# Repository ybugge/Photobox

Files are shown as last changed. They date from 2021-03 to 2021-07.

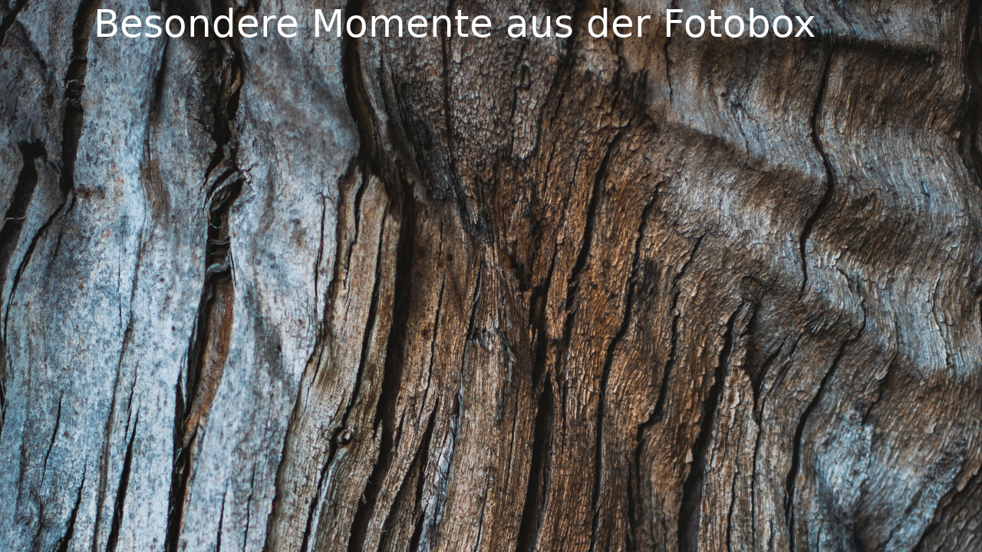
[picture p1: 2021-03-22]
Diashow/fromPhotobox/frame.png

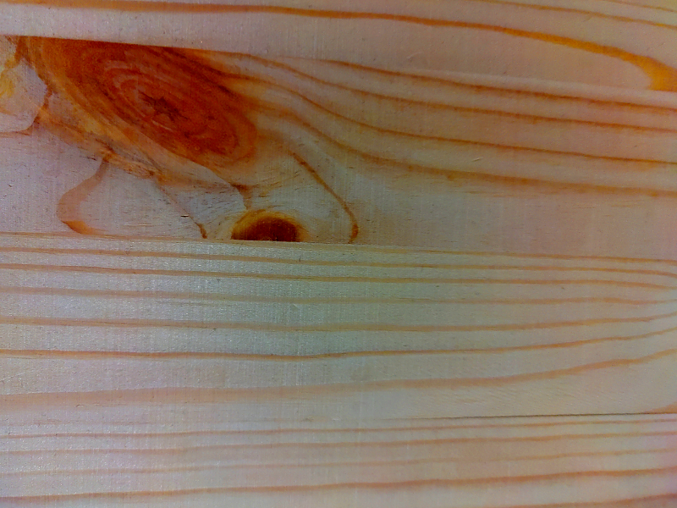
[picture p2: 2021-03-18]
Resources/PageTitlePicture/orig.png

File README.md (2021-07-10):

# Fotobox
Die Software wurde für den Raspberry PI entwickelt. Getestet wurde es auf dem Raspberry Pi 3 Model B+.
Entwickelt wurde es mit PyCharm in LinuxMint. Unter Windows funktioniert die Software nicht, da CUPS nicht von 
Windows unterstützt wird.

## Hardware
- Raspberry Pi 3 Model B+ -> https://www.raspberrypi.org/products/raspberry-pi-3-model-b-plus/
- Raspberry Pi High Quality Camera -> https://www.raspberrypi.org/products/raspberry-pi-high-quality-camera/
- Raspberry Pi Touch Display -> https://www.raspberrypi.org/products/raspberry-pi-touch-display/
- 16 GB SD-Karte
- Mini Wireless Keyboard Remote X8 -> http://www.riitek.com/product/x8.html
- Fritz!Box 4020 -> https://avm.de/produkte/fritzbox/fritzbox-4020/
- Canon SELPHY CP1300 -> https://www.canon.de/printers/selphy-cp1300/
- 2 USB Sticks für Fotos und Musik

Optional:
- UGREEN Externe USB Soundkarte -> https://www.amazon.de/UGREEN-Externe-Soundkarte-Computer-External/dp/B01N905VOY/ref=sr_1_10
- Kühlung -> https://www.amazon.de/MakerHawk-R%C3%BCstungskoffer-Himbeer-Pi-Metallgeh%C3%A4use-Doppel-L%C3%BCfter-Aluminiumlegierung-integrierter/dp/B07M7M53LT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

### Gehäuse
- Holzbox (außen: 40x30x24cm)(innen:37,5x27,5x21cm) -> https://www.amazon.de/LAUBLUST-Gro%C3%9Fe-Holzkiste-Deckel-Geschenk-Verpackung/dp/B016UYX344
- Kistengriffe -> https://www.amazon.de/ueetek-Edelstahl-schwere-stabile-Toolbox/dp/B079CF95Z9
- Aufnahme für das Dreibein -> https://www.amazon.de/Stagg-9709-Externer-Boxenflansch-Anschrauben/dp/B000OR5YE6
- Dreibein -> https://www.amazon.de/gp/product/B07PXQQ6Q1/ref=ppx_yo_dt_b_asin_title_o06_s00
- Schloss -> https://www.amazon.de/gp/product/B083LKFKQW/ref=ppx_yo_dt_b_asin_title_o07_s00
- Schnapper (damit der Deckel zu bleibt) -> https://www.amazon.de/gp/product/B07M67WJJR/ref=ppx_yo_dt_b_asin_title_o07_s01
- Rundstab: 20,5cm x 0,5cm (Essstäbchen)
- Brillenputztuch 
- Sperrholz (37,5cm x 19,0cm x 0,4cm)
- Aufbewahrungsbox (24,5cm x 18cm x 16 cm) (Really Useful Box Aufbewahrungsbox 3C 3 L)-> https://www.ebay.de/itm/362899377740?hash=item547e7d0e4c:g:udIAAOSwOQpftiw6

####Holzbox Maße:
Ausrichtung: Deckel zu mir gerichtet und wenn er offen ist, liegt er auf dem Boden.

Außen (mit Deckel): 
- 232mm (Tief)
- 293mm (Hoch)
- 395mm (Breit)

Außen (ohne Deckel):
- 197mm (Tief)
- 293mm (Hoch)
- 395mm (Breit)

Innen (mit Deckel):
- 212mm (Tief)
- 278mm (Hoch)
- 378mm (Breit)

Innen (ohne Deckel):
- 185mm (Tief)
- 278mm (Hoch)
- 378mm (Breit)

Wandstärke: ca. 9mm

#####Löcher:

Drucker:
- 120mm (Tief) x 35mm (Breit)
- Pos: 21cm (von vorne-Außen) x 15mm (von unten-Außen) 

Bildschirm:
- 105mm (Hoch) x 175mm (Breit)
- Pos: Unten anliegend mittig 

Kamera:
- 50mm (Hoch) x 42mm(Breit)
- Pos: 62mm (von oben Außen) x mittig

Stromanschluss:
- 29mm(Breit) x 56 (Hoch)
- Pos: 20mm (Von der Seite-Außen) 81mm (von Hinten-Außen)

##### Position:

Zwischenboden:
- Pos: 90mm (von unten-Innen) (Unterkante des 3D-Objekts)

Steckdose:
- Pos: 30mm (von vorne-Innen) so hoch wie möglich

Drucker-Grundplatte:
- Pos: 61mm (von Seite-Innen) so weit hinten wie möglich
   
### Elektrik
- Verteiler 4fach -> https://www.amazon.de/REV-STECKDOSE-PlanoLuxe-Mehrfachsteckdose-Innenbereich/dp/B00C25WRZW
- Kabel -> https://www.amazon.de/Bachmann-202275-Eurozuleitung/dp/B001ZT6VP8
- Hauptschalter mit Sicherung (Trennt Neutralleiter und Last) -> https://www.amazon.de/Hifi-Lab-Einbau-Stecker-Einbau-Buchse-Kaltgeräte-Buchse/dp/B01H5MK3OI
- Lichtschalter -> https://www.amazon.de/gp/product/B074VCBVKJ/ref=ppx_yo_dt_b_asin_title_o08_s00
- Lampen (2 Stück) -> https://www.reichelt.de/deckenleuchte-8-w-560-lm-3000-k-oval-vt-1311-p201362.html?&trstct=pos_3&nbc=1

### Optionale Kleinigkeiten
- Live Soundcard V8 -> https://www.ebay.de/itm/203511744223?hash=item2f623ec6df:g:gg4AAOSwn5lg3nA4
- Mikrofon
- Fotostudio (2.6M x 3M) -> https://www.amazon.de/gp/product/B0799BQJWX/ref=ppx_yo_dt_b_asin_title_o00_s00
- JBL Partybox 300 (2 mal) -> https://de.jbl.com/party-lautsprecher/JBL+PartyBox+300.html
- LTE Router -> https://www.amazon.de/TP-Link-M7200-Download-kompatibel-europ%C3%A4ischen-schwarz/dp/B079GZNQ2B/ref=sr_1_6

##Install
Die nachfolgende Instalation wurde mit LinuxMint durchgeführt.
Der Raspberry Pi wird ab jetzt Pi genannt. 

Auf LinuxMint:
````
$ sudo apt update
$ yes | sudo apt install rpi-imager
$ rpi-imager
````
- Operation Systenm = Raspberry PI OS (32-bit) (Recommanded)
- SD Card = Die zu verwendete SD-Karte
- "Write"
- "Yes"
- SD-Karte entnehmen und in den Pi stecken
- Raspberry Pi einschalten

Auf Raspberry Pi:
- Welcome to Raspberry Pi:
  - IP-Adresse aufschreiben: 192.168.188.22
  - Klicken: "Next"
  - Sprache einstellen und "Next" 
  - neues Passwort vergeben und "Next"
  - Bildschirmeinstellungen -> "Next"
  - Wifi eingeben wenn nötig. In meinem Fall ist der Pi mit dem Router über LAN verbunden 
  - Updates -> Next 
  - Pi neustarten 
 - Starten: "Raspberry-Pi-Konfiguration" unter "Start > Einstellungen"
   - Tab -> "System"
   - Aktivieren: "Auf Netzwerk warten"
   - Tab -> "Schnittstellen"
   - Aktivieren: "Kamera"
   - Aktivieren: "SSH"
   - Tab -> "Display"
   - Deaktivieren: "Screen Blanking"
   - "OK"
   - Restart? -> "Ja"
  
Auf der Fritzbox
- LinuxMint: mit der Fritzbox verbinden
- Browser öffnen und die Seite "fritz.box/" aufrufen
- Einloggen
- Heimnetz > Netzwerk > Pi raussuchen bsp:192.168.188.22 > Auf "Stift" klicken
- "Name" = photobox
- Aktivieren: "Diesem Netzwerkgerät immer die gleiche IPv4-Adresse zuweisen."
- "OK"

Auf LinuxMint:
- Terminal öffnen 
````
$ ssh pi@photobox
$ yes
$ -> Passwort eingeben 
$ sudo apt update
$ yes | sudo apt upgrade 
$ yes | sudo apt install git
$ git clone https://github.com/ybugge/Photobox.git
$ cd Photobox
$ ./setupPhotobox.sh
````

Netzwerk nach einer Minute neu starten:
````
$ sudo crontab -e
@reboot /bin/sleep 60; /home/pi/Photobox/ShellScripts/restartNetwork.sh
STR+X -> Y -> ENTER 
````

##Drucker einrichten: Canon SELPHY CP1300 (W-LAN)
Quelle: 
- https://raspberrytips.com/install-printer-raspberry-pi/
- https://youtu.be/Gd0RKYRNJmo?t=570

PPD-Profile:
- 1.) https://cloud.voss.earth/index.php/s/SAi2M2na5KtR3gm -> https://www.voss.earth/2018/08/31/kurztipp-canon-selphy-wlan-drucker-cp910-oder-cp1300-unter-linux-cups-verwenden/
- 2.) https://www.objektiv-guide.de/icc-profil-canon-selphy/ -> Forum: https://www.dslr-forum.de/showthread.php?s=c6704e889a4db8e35e09f900192a341d&t=1865472&page=4

Browser->Pi: localhost:631

- Drucker und Klassen hinzufügen
- Drucker hinzufügen
- Eingabe: Benutzername und Passwort
- Drucker auswählen: (Netzwerkdrucker) Canon SELPHY CP1300 (Canon SELPHY CP1300)  
- Weiter
- Weiter
- PPD-Datei: Datei auswählen
- Photobox/PrinterPPD/Canon_SELPHY_CP1300.ppd
- Öffnen
- Drucker hinzufügen
- Color Mode: Color
- Media Size: Postcard.Fullbleed
- MediaType: Any
- Standardeinstellungen festlegen 

Hinweis:
1. Folgende Einstellung sollte an dem Drucker vorgenommen werden:
- WLAN-Einstellungen > Verbindungsmethode > Über WLAN-Netzwerk = Mit der Fritzbox verbinden.
- Setup > Drucker Setup >auto.Abschalten = Aus

# Diashow Client

## Hardware
- Raspberry Pi Zero W -> https://www.raspberrypi.org/products/raspberry-pi-zero-w/
- 16GB SD-Karte
- TV

## Install
Die nachfolgende Instalation wurde mit LinuxMint durchgeführt.
Der Raspberry Pi Zero W wird ab jetzt Pi genannt. 

Auf LinuxMint:
````
$ sudo apt update
$ yes | sudo apt install rpi-imager
$ rpi-image
````
- Operation Systenm = Raspberry PI OS (32-bit) (Recommanded)
- SD Card = Die zu verwendete SD-Karte
- "Write"
- "Yes"
- SD-Karte erneut in LinuxMint stecken
  - Ordner "boot" öffnen 
  - Datei "ssh" erstellen
  - Datei "wpa_supplicant.conf" erstellen 
  - folgendes eintragen: siehe https://www.raspberrypi.org/documentation/configuration/wireless/headless.md
```
ctrl_interface=DIR=/var/run/wpa_supplicant GROUP=netdev
update_config=1
country=<Insert 2 letter ISO 3166-1 country code here>

network={
 ssid="<Name of your wireless LAN>"
 psk="<Password for your wireless LAN>"
}
```
- SD-Karte entnehmen und in den Pi stecken
- Raspberry Pi einschalten

Auf Linux Mint:
- Terminal öffnen:
````
$ ssh pi@<ip-adresse>
$ yes
$ password = raspberry
$ sudo raspi-config
System Options > Password > "Durchführen"
System Options > Network at Boot > Yes
Display Options > Underscan > No 
Display Options > Screen Blanking > No
Finish
Reboot > Yes
$ git clone https://github.com/ybugge/Photobox.git
$ cd Photobox
$ ./setupDiashow.sh
````

-> Auflösung: 1280x720
# Zusätzliche Hinweise:

# Musikserver:
## Bluetoothe Geräte verbinden (Allgemein)
Quellen:
- https://raspberrydiy.com/connect-raspberry-pi-bluetooth-speaker/

Auf dem Raspberry Pi (Oberfläche):
- Bluetooth-Symbol klicken
- Add Device
- Bluetoothgerät auswählen 
- Auf dem Lautspächer-Symbol rechtsklick
- Bluetoothgerät auswählen

##Mopidy
Quellen: 
- https://www.pcwelt.de/a/musikserver-mopidy-auf-raspberry-pi,3447697
- https://braspi.de/blogs/braspi-blog/raspberry-pi-als-musik-server-mit-mopidy
- https://magpi.raspberrypi.org/articles/make-a-raspberry-pi-audio-player-with-mopidy-music
- https://wiretuts.com/installing-mopidy-music-server-on-raspberry-pi
- https://docs.mopidy.com/en/latest/installation/raspberrypi/#how-to-for-raspbian
- Mopidy Local: https://pypi.org/project/Mopidy-Local/
- Permission denied: https://discourse.mopidy.com/t/mopidy-scan-usb-not-successful/4722/5
- https://discourse.mopidy.com/t/iris-and-mopidy-mobile-are-empty-when-music-is-on-usb-drive/4280/4
- Mopidy Error: https://discourse.mopidy.com/t/problem-scanning-local-flac-files/4823/3

###Wichtige Befehle:
- Konfiguration anzeigen:
````
$ sudo mopidyctl config
````
- Konfiguration anpassen:
````
$ sudo nano /etc/mopidy/mopidy.conf
````
- Serverstatus anzeigen
````
$ sudo systemctl status mopidy
````
- Starten/ Stoppen / Restart Server
````
$ sudo systemctl start/stop/restart mopidy
````
- Lokale Konfiguration anzeigen: (Template)
````
$ sudo nano /home/pi/.config/mopidy/mopidy.conf
````

### Instalation
Auf dem Raspberry Pi (SSH-Terminal):

````
$ sudo apt update
$ yes | sudo apt upgrade
USB-Stick, auf die die Musik vorhanden ist, einstecken. (Format: Fat32)
$ ls -l /dev/disk/by-label/
$ ls -l /dev/disk/by-uuid/
- UUID von Musikstick raus suchen: Bsp: FA43-EF95
$ sudo nano /etc/fstab
UUID=FA43-EF95 /media/usbMusic vfat auto,nofail,umask=000,noatime,users,rw,uid=mopidy,gid=audio 0 0
$ sudo reboot

$ wget -q -O - https://apt.mopidy.com/mopidy.gpg | sudo apt-key add -
$ sudo wget -q -O /etc/apt/sources.list.d/mopidy.list https://apt.mopidy.com/buster.list
$ sudo apt update
$ sudo apt install mopidy python3-pip libspotify-dev
$ sudo python3 -m pip install Mopidy-Youtube Mopidy-Local Mopidy-MusicBox-Webclient Mopidy-TuneIn
$ sudo adduser mopidy video
$ sudo nano /etc/mopidy/mopidy.conf

[http]
enabled = true
hostname = photobox
port = 6680

[audio]
#output = pulsesink server=127.0.0.1

[file]
enabled = true
media_dirs = /media/usbMusic|Home

[youtube]
enabled = false

[local]
enabled = true
media_dir = /media/usbMusic

[musicbox_webclient]
enabled = true
#musicbox = false

$ sudo mopidyctl config
$ sudo systemctl enable mopidy
$ sudo systemctl start mopidy
$ sudo systemctl status mopidy
- No Errors
$ mopidy local scan
$ sudo reboot
````

Im Browser: http://photobox.fritz.box:6680/mopidy/
Mit BluetoothBox:

Quelle: 
- https://wiretuts.com/connecting-bluetooth-audio-device-to-raspberry-pi
- https://www.wiretuts.com/connect-mopidy-to-bluetooth-speaker-on-raspberry-pi
````
Bluetooth gerät wir oben beschrieben mit Pi verbinden
$ sudo apt-get install pulseaudio*
$ sudo usermod -a -G lp pi
$ sudo reboot
$ sudo nano /etc/pulse/default.pa
- native-protocol-tcp -> Zwischenablage (Strg+C)
- Strg+W -> Strg+Umschalt+V 
- ersetzen mit -> load-module module-native-protocol-tcp auth-ip-acl=127.0.0.1
- Strg+X -> Y -> ENTER
$ sudo nano /etc/mopidy/mopidy.conf
[audio]
output = pulsesink server=127.0.0.1
$ pulseaudio -k
$ pulseaudio --start
$ sudo reboot
````

Dienst nach einereinhalb Minute neu starten:
````
$ sudo crontab -e
@reboot /bin/sleep 90; sudo systemctl restart mopidy
STR+X -> Y -> ENTER 
````

### Spotify

````
$ sudo systemctl stop mopidy
$ sudo python3 -m pip install Mopidy-Spotify
$ sudo nano /etc/mopidy/mopidy.conf
-> Folgende Zeilen Hinzufügen:  Kee generieren über -> https://mopidy.com/ext/spotify/
[spotify]
username = alice
password = secret
client_id = The config value will appear here. (siehe Keepass)
client_secret = The config value will appear here. (siehe Keepass)
$ sudo systemctl start mopidy
````

### Equalizer (Test)
Quelle: 
- https://www.addictivetips.com/ubuntu-linux-tips/install-pulseaudio-equalizer-on-linux/
- https://linuxhint.com/install-pulseaudio-equalizer-linux-mint/

````
$ sudo apt install pavucontrol
$ sudo apt install pulseaudio-equalizer
start equalizer
$ qpaeq
$ sudo nano /etc/pulse/default.pa
- Hinzufügen:
load-module module-equalizer-sink
load-module module-dbus-protocol
$ pulseaudio --kill && pulseaudio --start
$ qpaeq
````

### Weiterer Adons:
- https://mopidy.com/ext/tunein/
- https://mopidy.com/ext/spotify/ 
- YoutubeAPI:
  - https://www.youtube.com/watch?v=ozOmQGDVwKQ

## Backup erstellen

Quelle: https://www.bitblokes.de/sd-karte-des-raspberry-pi-sichern-dd-oder-partclone/
````
- SD-Karte vom Pi in Rechner stecken
- Konsole öffnen (Fragezeichen ersetzen)
$ sudo dd if=/dev/sd???? | gzip > /home/ybugge/Dokumente/photobox-dd.gz
- neue SD Karte einstecken. Darf aber nicht eingehangen sein.
$ sudo gzip -dc /home/ybugge/Dokumente/photobox-dd.gz | dd of=/dev/sd???
````

## Verbesserungsvorschläge
- Titelbild und Rahmen der Diashow über die Fotobox beziehen.

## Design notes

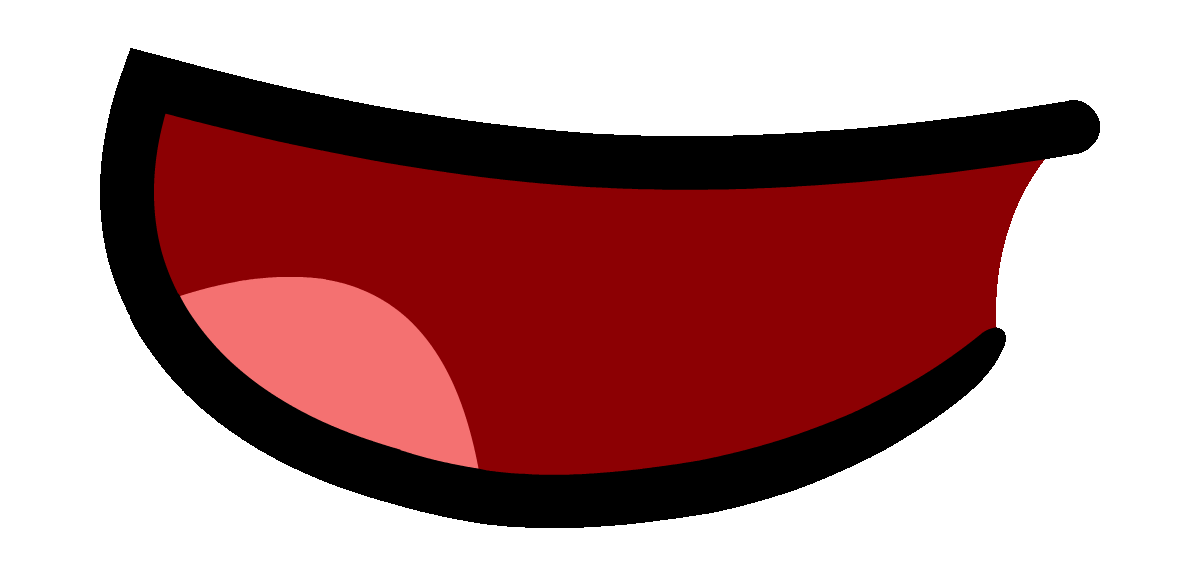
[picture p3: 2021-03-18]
Resources/PageTitlePicture/Smiley/smile1.png

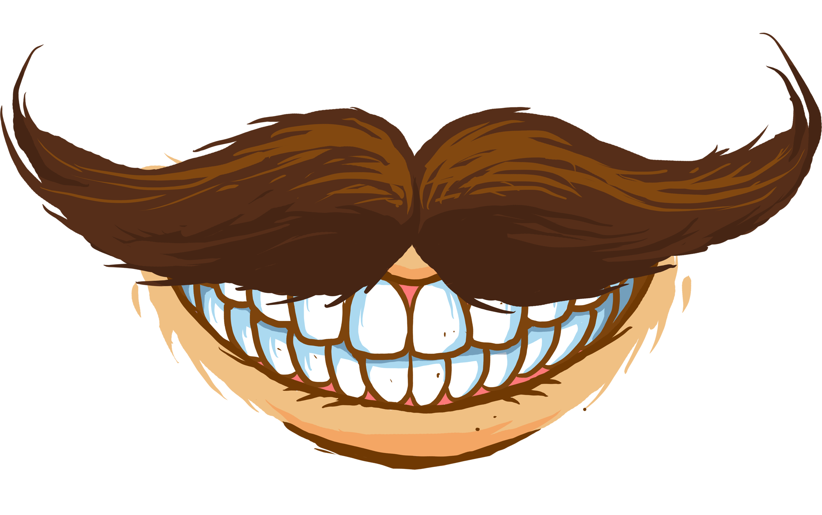
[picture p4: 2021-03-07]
Resources/PageTitlePicture/Smiley/smile5.png

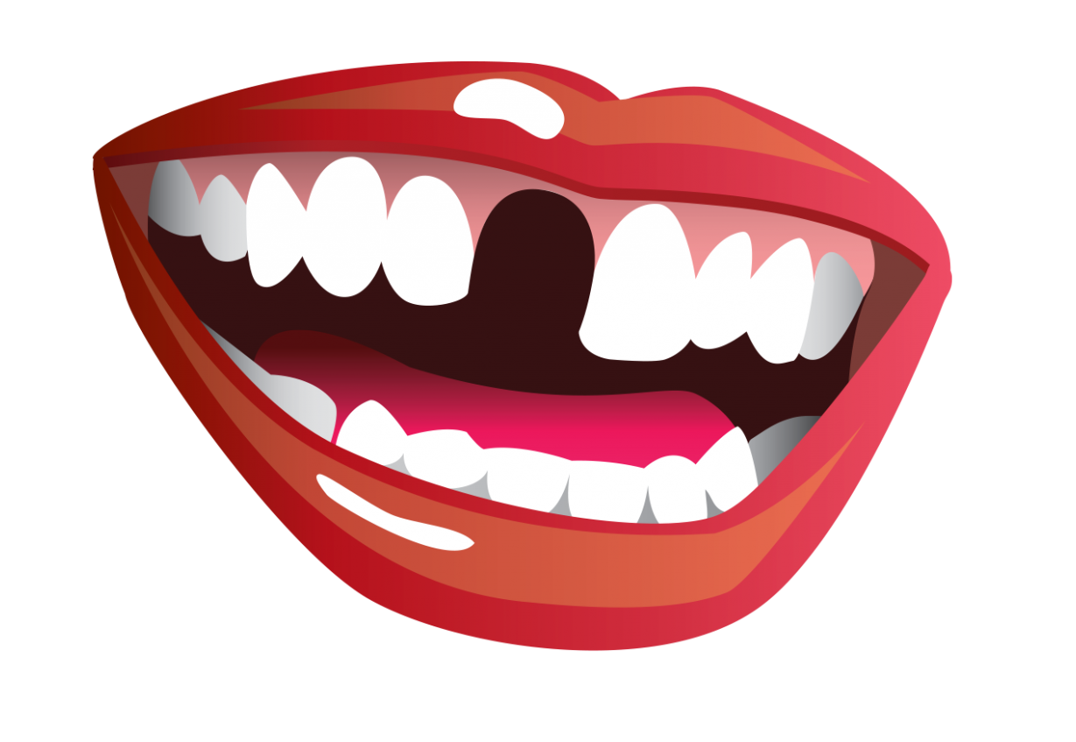
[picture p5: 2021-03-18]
Resources/PageTitlePicture/Smiley/smile3.png

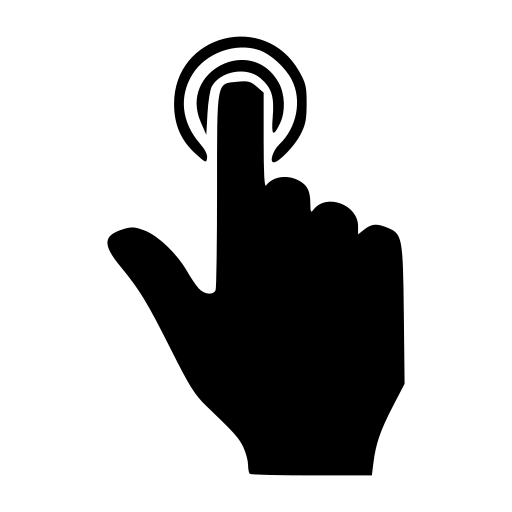
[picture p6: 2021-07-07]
Resources/PageTitlePicture/touch.png

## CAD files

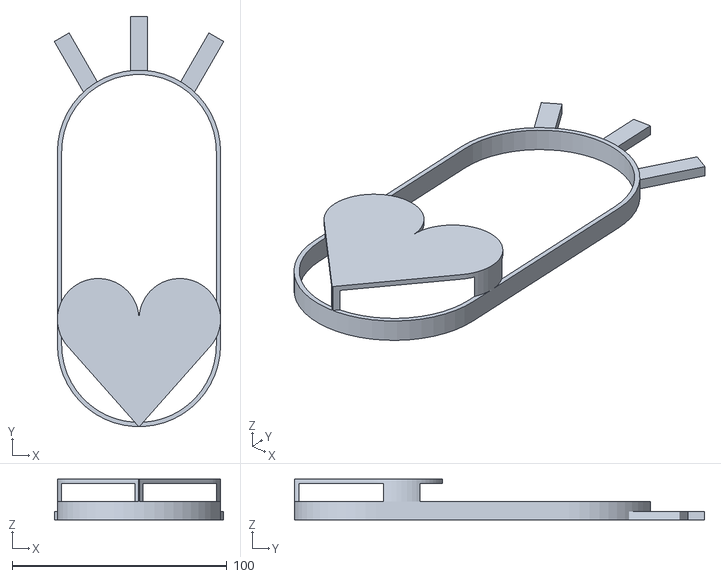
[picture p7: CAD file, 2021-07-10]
Hardware/3dModels/Augen/Auge2_rechts.stl
78.9 x 190.9 x 19.0

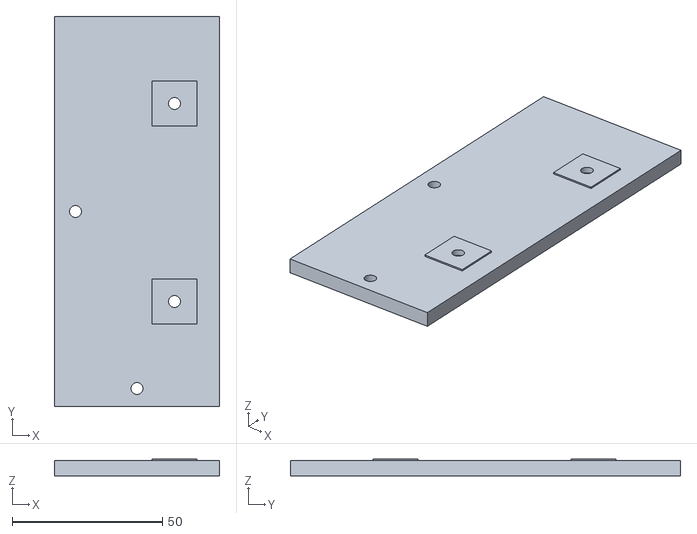
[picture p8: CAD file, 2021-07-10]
Hardware/3dModels/Display/Display_Halter_rechts.stl
55.0 x 130.0 x 5.50

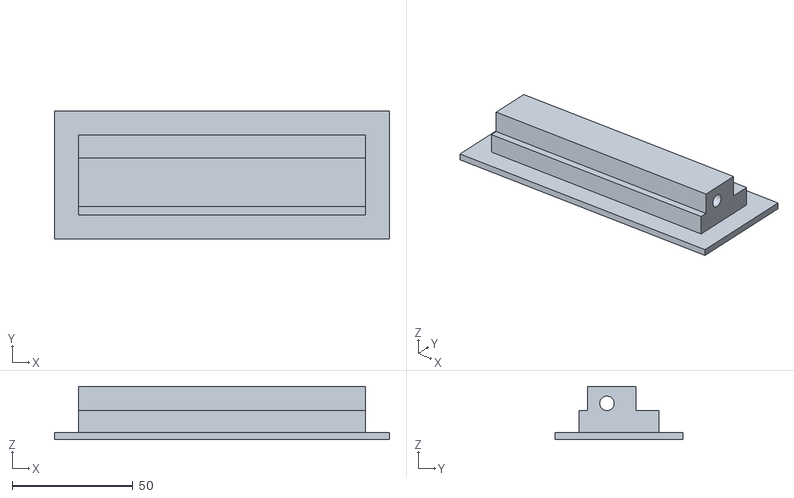
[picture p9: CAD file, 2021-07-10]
Hardware/3dModels/Drucker/Drucker_PapierschachtCover.stl
139.0 x 53.0 x 22.0

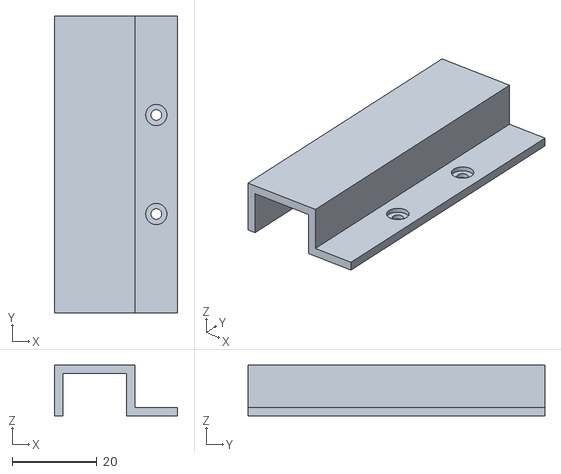
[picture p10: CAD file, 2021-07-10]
Hardware/3dModels/Kabelkanal/Kabelkanal_Deckel_seite_oben.stl
29.0 x 70.0 x 12.0

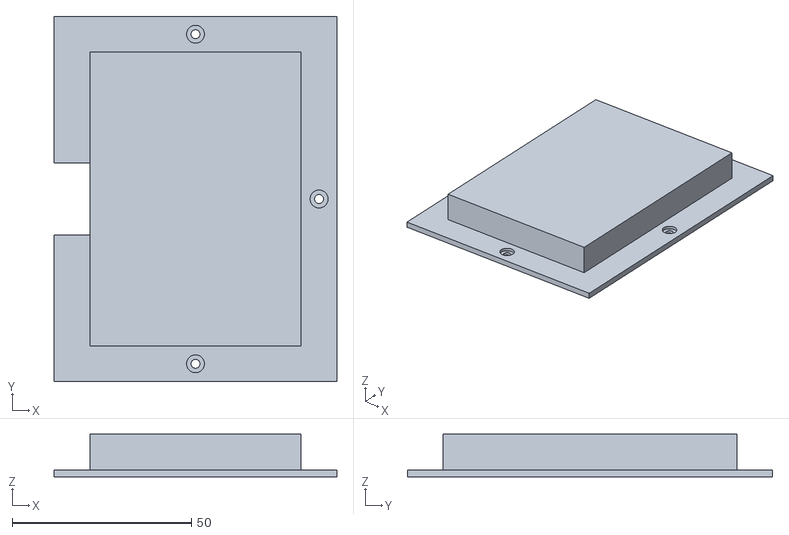
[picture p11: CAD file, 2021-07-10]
Hardware/3dModels/Kamera/Kamera_Abdeckung_hinten.stl
79.0 x 102.0 x 12.0

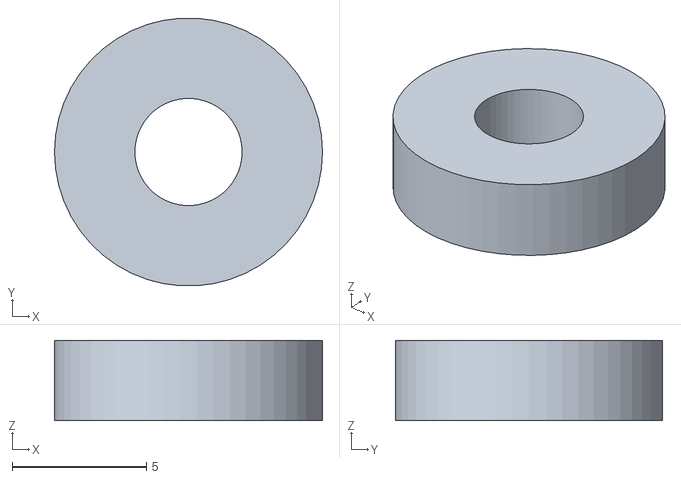
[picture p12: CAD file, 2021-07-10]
Hardware/3dModels/Router/Router_Unterlegscheibe.stl
10.0 x 9.98 x 3.00

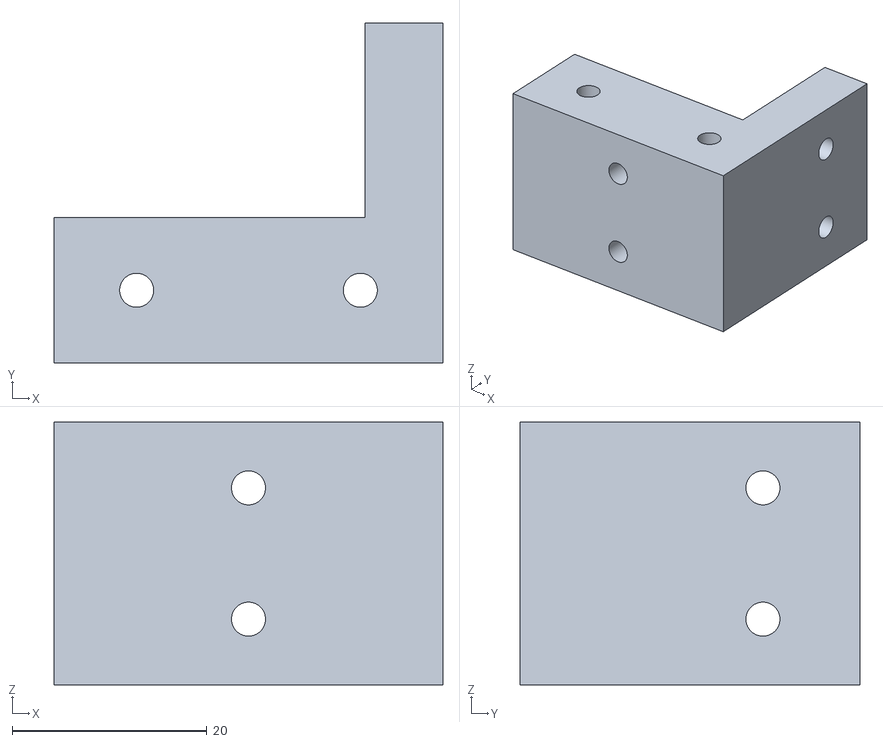
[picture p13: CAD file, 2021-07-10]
Hardware/3dModels/Schnapper/Schnapper_Deckel_Distanzstueck_rechts.stl
40.0 x 35.0 x 27.0

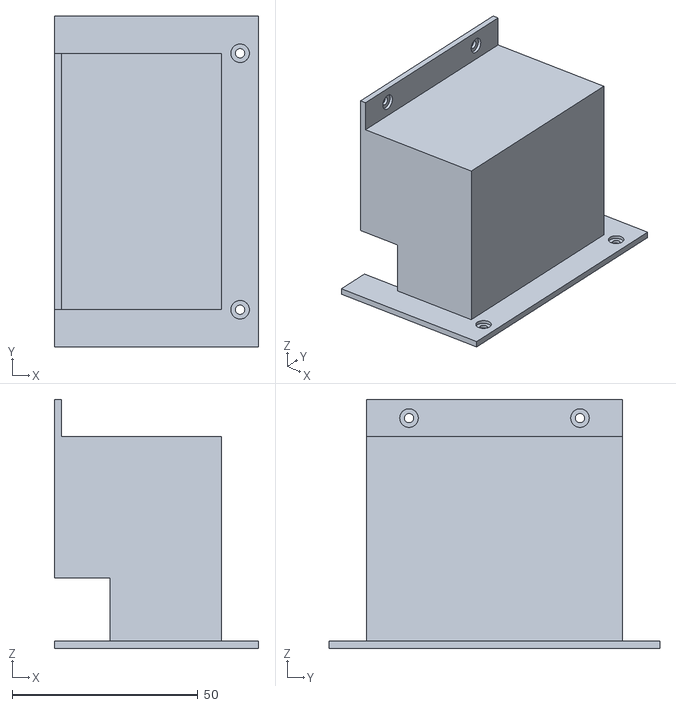
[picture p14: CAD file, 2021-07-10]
Hardware/3dModels/Stromanschluss/Stromanschluss_Abdeckung.stl
55.0 x 89.0 x 67.0

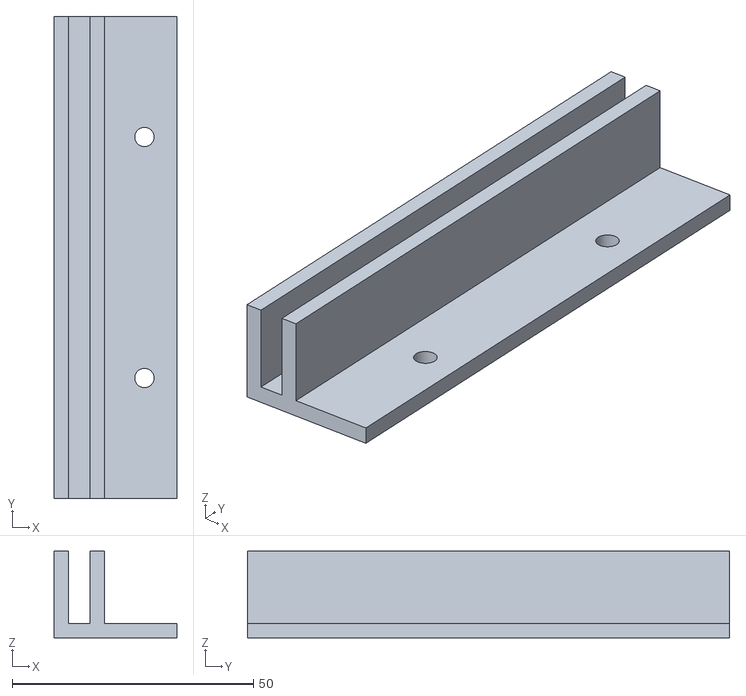
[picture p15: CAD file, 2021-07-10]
Hardware/3dModels/Zwischenwand/Zwischenwand_Halter_seite.stl
25.5 x 100.0 x 18.0

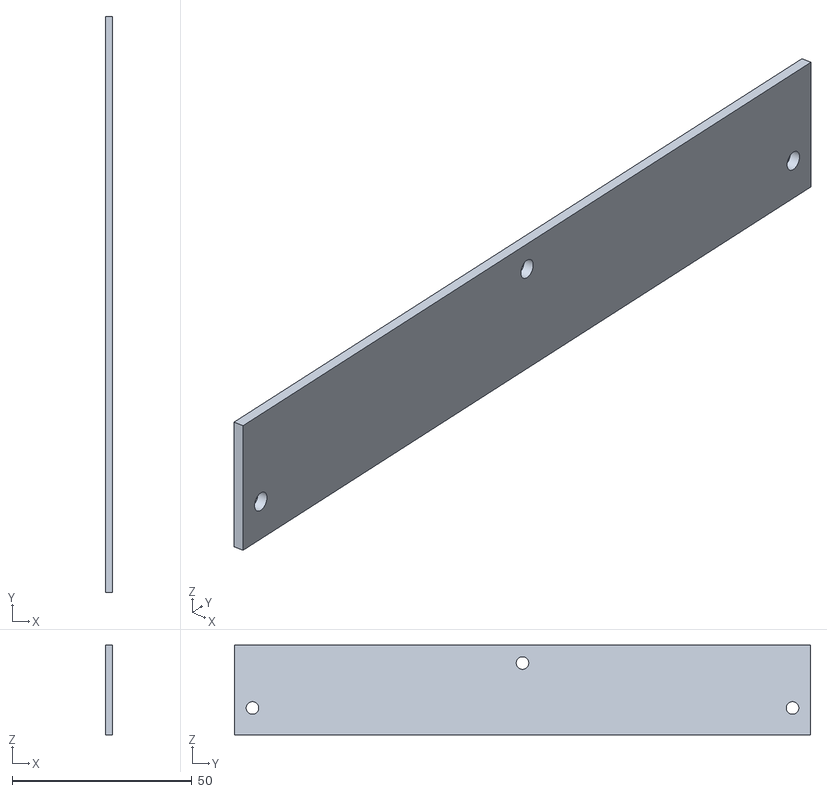
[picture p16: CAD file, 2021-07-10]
Hardware/3dModels/Drucker/Drucker_Halter_Hinten_Stuetzplatte.stl
2.00 x 160.3 x 25.0

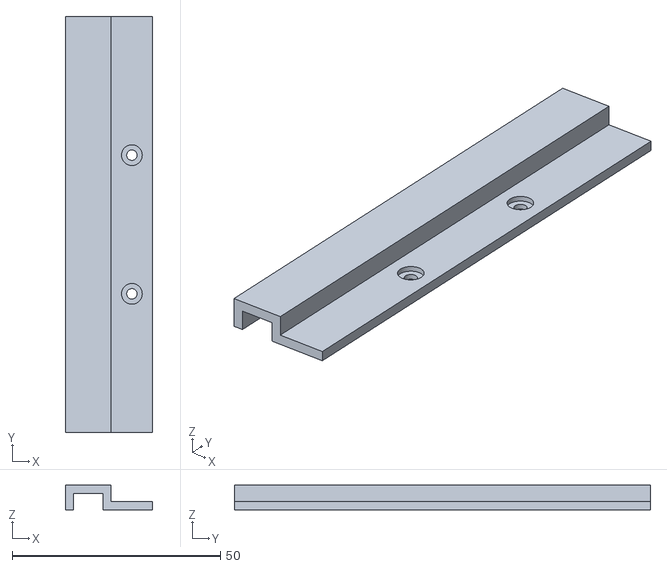
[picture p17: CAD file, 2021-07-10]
Hardware/3dModels/Kabelkanal/Kabelkanal_Deckel_oben.stl
21.0 x 100.0 x 6.00

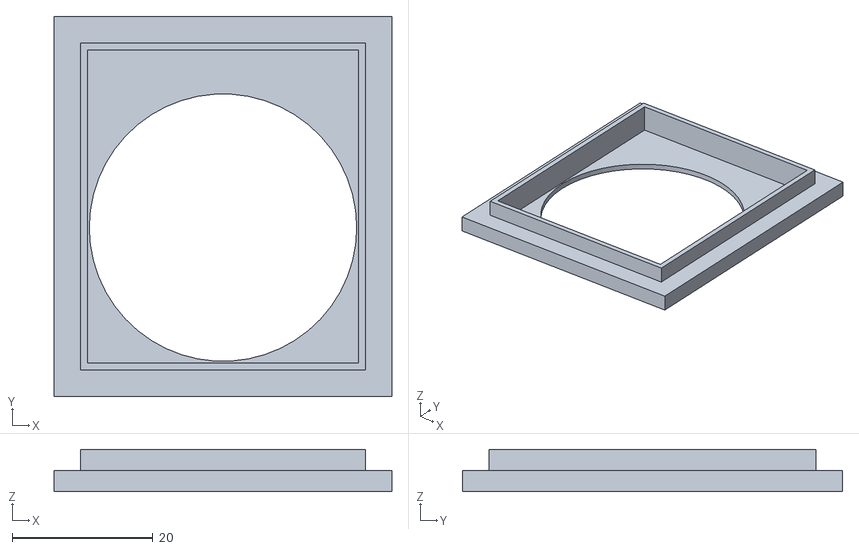
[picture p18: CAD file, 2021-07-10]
Hardware/3dModels/Kamera/Kamera_Abdeckung.stl
48.0 x 54.0 x 6.00

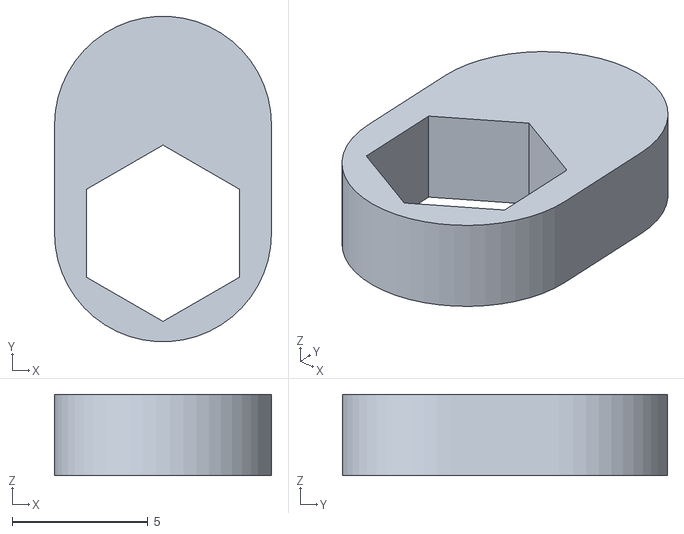
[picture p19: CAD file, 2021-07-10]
Hardware/3dModels/Router/Router_Mutter_Abdeckung.stl
8.00 x 12.0 x 3.00

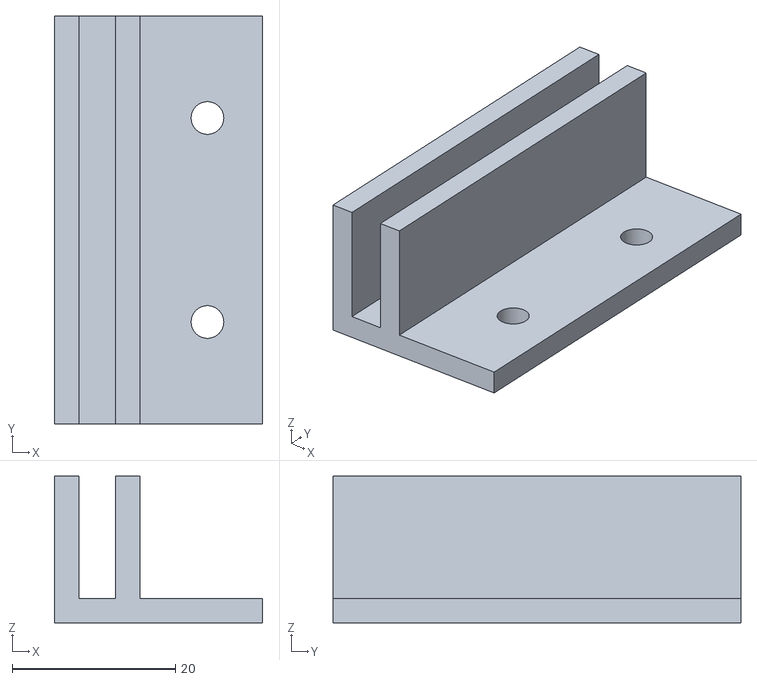
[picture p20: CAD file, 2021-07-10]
Hardware/3dModels/Zwischenwand/Zwischenwand_Halter_hinten.stl
25.5 x 50.0 x 18.0

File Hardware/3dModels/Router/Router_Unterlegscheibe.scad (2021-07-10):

include <../lib/Photobox.scad>;

routerSpace();

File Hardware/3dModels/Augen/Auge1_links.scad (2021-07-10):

include <../lib/Photobox.scad>;

eyes2();

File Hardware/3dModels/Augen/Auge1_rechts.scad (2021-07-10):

include <../lib/Photobox.scad>;

mirror([1,0,0])
eyes2();

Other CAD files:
Hardware/3dModels/Augen/Auge2_links.stl
Hardware/3dModels/Display/Display_Halter_links.stl
Hardware/3dModels/Schnapper/Schnapper_Deckel_Distanzstueck_links.stl
Hardware/3dModels/Augen/Auge4_rechts.stl
Hardware/3dModels/Augen/Auge2_links.scad
Hardware/3dModels/Augen/Auge1_links.stl
Hardware/3dModels/Augen/Auge1_rechts.stl
Hardware/3dModels/Augen/Auge2_rechts.scad
Hardware/3dModels/Augen/Auge3_links.scad
Hardware/3dModels/Augen/Auge3_links.stl
Hardware/3dModels/Augen/Auge3_rechts.scad
Hardware/3dModels/Augen/Auge3_rechts.stl
Hardware/3dModels/Augen/Auge4_links.scad
Hardware/3dModels/Augen/Auge4_links.stl
Hardware/3dModels/Augen/Auge4_rechts.scad
Hardware/3dModels/Display/Display_Halter_links.scad
Hardware/3dModels/Display/Display_Halter_rechts.scad
Hardware/3dModels/Drucker/Drucker_Halter_Boden.scad
Hardware/3dModels/Drucker/Drucker_Halter_Boden.stl
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

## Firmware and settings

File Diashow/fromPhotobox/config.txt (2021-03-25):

from_server=True
frame_front=True
picture_size_percent_xy=80
picture_move_percent_x=50
picture_move_percent_y=48

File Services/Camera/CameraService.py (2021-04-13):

from PyQt5.QtCore import QSize
from PyQt5.QtMultimedia import QCameraInfo

from Services.Camera.CV2CapturePhotoThread import CV2CapturePhotoThread
from Services.Camera.CV2GreenscreenCalibrationService import CV2GreenscreenCalibrationService
from Services.Camera.CV2VideoThread import CV2VideoThread
from Services.Camera.PiCamGreenscreenCalibrationService import PiCamGreenscreenCalibrationService
from Services.Camera.PiCamPhotoThread import PiCamPhotoThread
from Services.Camera.PiCamVideoThread import PiCamVideoThread
from Services.CfgService import CfgService
from Services.GlobalPagesVariableService import GlobalPagesVariableService
from config.Config import cfgValue, CfgKey

try:
    from picamera import PiCamera
except ImportError:
    if cfgValue[CfgKey.IS_PI]:
        print("CameraService: PiCamera not found")

class CameraService():

    @staticmethod
    def existPiCamera():
        if cfgValue[CfgKey.USE_PI_CAMERA] == None:
            if cfgValue[CfgKey.IS_PI]:
                try:
                    camera = PiCamera()
                    camera.close()
                    cfgValue[CfgKey.USE_PI_CAMERA] = True
                except Exception as e:
                    print(e)
                    cfgValue[CfgKey.USE_PI_CAMERA] =  False
            else:
                cfgValue[CfgKey.USE_PI_CAMERA] =  False
        return cfgValue[CfgKey.USE_PI_CAMERA]

    #https://www.geeksforgeeks.org/creating-a-camera-application-using-pyqt5/
    @staticmethod
    def existCameras():
        camerasInfos = QCameraInfo.availableCameras()
        return len(camerasInfos) > 0

    @staticmethod
    def existSelectedCamera():
        camerasInfos = QCameraInfo.availableCameras()
        return len(camerasInfos) > CfgService.get(CfgKey.USED_CAMERA_INDEX)

    @staticmethod
    def getCameraIndex():
        return CfgService.get(CfgKey.USED_CAMERA_INDEX)

    @staticmethod
    def getCameraName():
        camerasInfos = QCameraInfo.availableCameras()
        cameraIndex = CameraService.getCameraIndex()
        return camerasInfos[cameraIndex].deviceName()

    @staticmethod
    def getCameraDescription():
        camerasInfos = QCameraInfo.availableCameras()
        cameraIndex = CameraService.getCameraIndex()
        return camerasInfos[cameraIndex].description()

    @staticmethod
    def initialAndStartVideo(img_dimensions:QSize,globalPagesVariable : GlobalPagesVariableService, setVideoStreamToLabel, background = None, hsvPixelLabel=None):
        if CameraService.existPiCamera():
            t_videoThread = PiCamVideoThread(img_dimensions,globalPagesVariable,background)
            if not hsvPixelLabel is None:
                t_videoThread.pixelHsv.connect(hsvPixelLabel)
            t_videoThread.changePixmap.connect(setVideoStreamToLabel)
            t_videoThread.start()
            return t_videoThread
        else:
            t_videoThread = CV2VideoThread(img_dimensions,globalPagesVariable,background)
            if not hsvPixelLabel is None:
                t_videoThread.pixelHsv.connect(hsvPixelLabel)
            t_videoThread.changePixmap.connect(setVideoStreamToLabel)
            t_videoThread.start()
            return t_videoThread

    @staticmethod
    def initialPhoto(globalVariable:GlobalPagesVariableService, background = None):
        if CameraService.existPiCamera():
            return PiCamPhotoThread(globalVariable,background)
        else:
            return CV2CapturePhotoThread(globalVariable,background)

    @staticmethod
    def initGreenscreenCalibrationCam(pictureSize:QSize):
        if CameraService.existPiCamera():
            return PiCamGreenscreenCalibrationService(pictureSize)
        else:
            return CV2GreenscreenCalibrationService(pictureSize)

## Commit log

2021-03-10 add camera calibration view
2021-03-12 add forward timer in Page
2021-03-16 add camera test file
2021-03-16 add pi camera video
2021-03-17 add camera shot photo with picam
2021-03-18 change button color.
2021-03-19 add Page print frame
2021-03-22 update diashow: add frame
2021-03-25 diashow change position and size from picture by config
    [config.txt]
2021-03-25 add printer install
2021-03-27 add select printer dropdown and add disable function in editpage
2021-03-27 add print feature
2021-03-28 add hint to startup the printer
2021-03-28 disable printbutton when click the button
2021-03-28 test printersettings
2021-03-28 test change printsize
2021-03-28 printer test
2021-03-28 test printer
2021-03-28 cut picturer to printer paper size
2021-03-28 update printer options
2021-03-28 add printer status
2021-03-28 add printer hints to hint page
2021-03-28 cant load printer, now the printerfeatures are disabeld
2021-03-28 server: add print page
2021-03-28 now printing is for web available
2021-03-29 fix: printer print now in full size
2021-03-29 add new Page: Reconfigure to disable the printer function
2021-03-29 is printing disabled, then redirect from printpage to picturepage
2021-03-29 add feature: pictures can't now endless printed
2021-03-30 fix printerstatus and printerstart in web
2021-04-02 update printer error message with red backgroundcolor
2021-04-02 update printer error message color
2021-04-19 add rotation button for backgrounds
2021-04-19 resize rotate button
2021-05-24 remove print in diashow
2021-06-26 add camera calibration in reconfig part
2021-06-26 disable printer in webui by config
2021-07-04 add favicon | web printing now with javascript.
2021-07-04 after starting the printing, the update service wait 10 seconds
2021-07-10 add 3d-Models
    [Auge1_links.scad, Auge1_links.stl, Auge1_rechts.scad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]
2021-08-25 add feature: disable auto brightness for pi camera
2021-08-29 disabled after und befor action from qr-code generator
